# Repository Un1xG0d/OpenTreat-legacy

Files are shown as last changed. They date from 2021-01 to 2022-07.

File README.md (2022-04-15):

<h1 align="center">
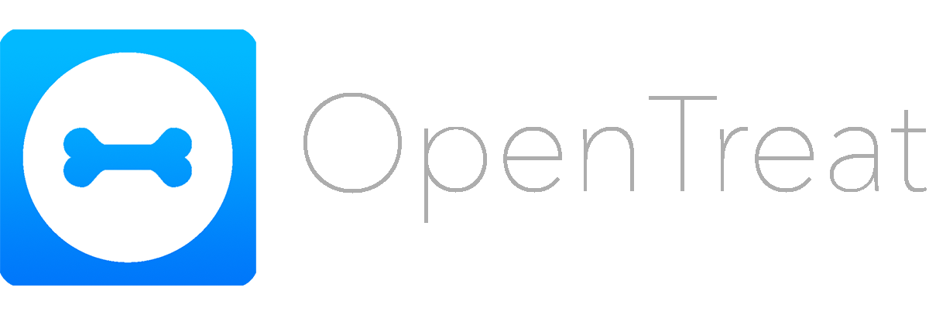
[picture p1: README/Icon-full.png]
  
</h1>

<div align="center">
	
	
	
</div>
<br>
<p>
OpenTreat allows a user to view and interact with their pets while not at home. Watch a live video stream of your pets from your smartphone or laptop, and remotely dispense treats with the push of a button.
</p>

:movie_camera: [Watch video demo of OpenTreat](https://youtu.be/6tzPRBlFip4) :movie_camera:

## Treat dispenser system
### Overview
The treat dispenser system is built using a Raspberry Pi and 3D printed parts. When a user presses the button on the webapp, a Python script is executed on the Pi to turn the servo motor for a certain number of seconds. The servo motor turns the 3D printed auger and pushes the treat down the tube where it drops out the end and into the feeding bowl.

### Parts needed
* Raspberry Pi
* LS3006 servo (any 360* servo should work)
* 3D printer
* USB webcam

### Physical assembly
1. Download and 3D print each STL listed in the `models` folder
	1. The recommended print settings are in the Resources section below
2. Assemble the parts using super glue
3. Use the pinout diagram in the Resources section (or find one for your RPi model) to hook up the 3 servo wires to the Raspberry Pi’s GPIO pins

### Configure ngrok
OpenTreat utilizes [ngrok](https://ngrok.com/docs) to securely expose the PHP pages to the internet. An annual Basic plan subscription allows you to create stable, custom subdomains for your dispensers. This is needed before running the script to populate the templates.

```
cd ~/
wget https://bin.equinox.io/c/4VmDzA7iaHb/ngrok-stable-linux-arm.tgz
tar xf ngrok-stable-linux-arm.tgz
/home/pi/ngrok authtoken 1hTfjOEDlX771y5WHDHL4bCZ1gc_81262WDRezREwGHuxX8pJ
```

### Register for free TURN server account
Create a free account on http://numb.viagenie.ca. You will need the server & login details you receive via email to run `populate_templates.sh`.

### Clone the repo into a folder called OpenTreat in your Pi's home directory
```
git clone https://github.com/psycoder17/OpenTreat.git ~/OpenTreat/src
cd ~/OpenTreat/src/
```

### Generate personalized files from code templates
```
bash populate_templates.sh
```

### Test the servo script on your Raspberry Pi
A Python3 script takes advantage of the Raspberry Pi’s GPIO pins to send a signal to the servo motor when a user presses the treat button on the webapp. The script turns the servo for a set number of seconds to push the treat through the tube and drop it down at the end.

### Install Python dependencies
```
pip3 install -r python/requirements.txt
```

### Manually execute the script to test that the servo/auger spins
```
python3 python/rotate_auger.py
```

Now that your Raspberry Pi properly dispenses treats when the Python script runs, Apache needs to be setup to host a PHP file that executes the Python script when the browser is redirected to `<Raspberry Pi IP>:80/spin.php`.

### Configure Apache server
```
sudo bash rpi-www/setup.sh
```

Then add `www-data ALL=(root) NOPASSWD: /sbin/reboot ` to your `/etc/sudoers` file to allow the www-data user to reboot the Pi.

At this point the servo connected to the RPi should now spin when visiting `<Raspberry Pi IP>/spin.php` in a web browser.

### Configure Apache secrets
Due to account restrictions and permission errors with the `www-data` user, we need to run the `broadcast_webcam.py` script as user `pi`. Instead of hardcoding the Pi's password into the project's source code, we can set an environment variable that reads from the file `/var/www/secrets/pipw`.

```
sudo mkdir /var/www/secrets/
sudo chown pi:root /var/www/secrets/
echo "PI_PW=<pi-user-account-password>" > /var/www/secrets/pipw
echo "NGROK_PW=<ngrok-basic-auth-password>" >> /var/www/secrets/pipw
```

> Remember to replace `<pi-user-account-password>` with the password you set for `pi` when initially configuring your Raspberry Pi. `<ngrok-basic-auth-password>` should be set here **and** as a Config Var on the Settings page of your Heroku application.

## Video stream app
The video streaming app is built with Javascript using NodeJS, Express, WebRTC, and Socket.IO. The webapp is hosted in Heroku and allows a user to login and view the video stream being broadcasted from the Pi's webcam.

### Deploy the video streaming app to Heroku
```
cd js/

heroku create <my-opentreat-project>

git add .
git commit -m "commit message"
git push heroku master
```

If everything was successful you can now browse to `https://<my-opentreat-project>.herokuapp.com/broadcast` on your Raspberry Pi to manually start broadcasting the Pi's webcam to your webapp on Heroku.

## Usage
### Automatic startup
Create a cronjob with `crontab -e` to run a Python script on boot to automatically broadcast the Pi's webcam to the webapp hosted on Heroku. The shell script configures and launches the ngrok tunnel.

```
@reboot python3 /var/www/html/broadcast_webcam.py
@reboot /bin/bash /var/www/html/ot_ngrok.sh
```

### View the video stream
On your smartphone or laptop, browse to `https://<my-opentreat-project>.herokuapp.com` to view the video stream of your pets. 
Press the bone button to spin the auger and drop treats into your pets' bowl. 
The orange button restarts the webcam broadcast.
The red button reboots the Raspberry Pi.

## Resources
### Links
[Viagenie.ca: free TURN servers](http://numb.viagenie.ca)

[Thingiverse: original fish feeder model](https://www.thingiverse.com/thing:301532)

[GitHub: original WebRTC broadcasting webapp](https://github.com/TannerGabriel/WebRTC-Video-Broadcast)

### Recommended print settings
> Scale: 100%  
> Infill: 30%  
> Layer Height: 0.2  
> Speed: Standard  
> Supports: None

### RPi GPIO diagram
> Red wire - Pin 1 - 3v3 power  
> Black wire - Pin 6 - ground  
> Orange wire - Pin 11 - GPIO 17  



### Screenshots & proof-of-concept
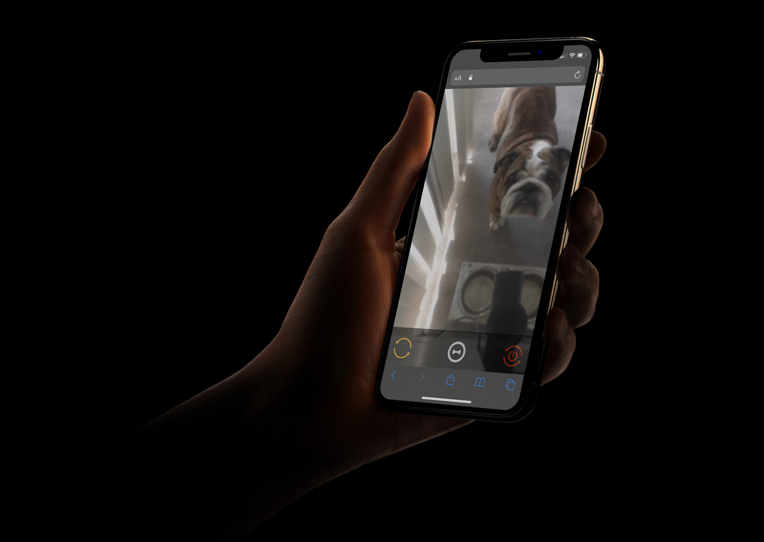
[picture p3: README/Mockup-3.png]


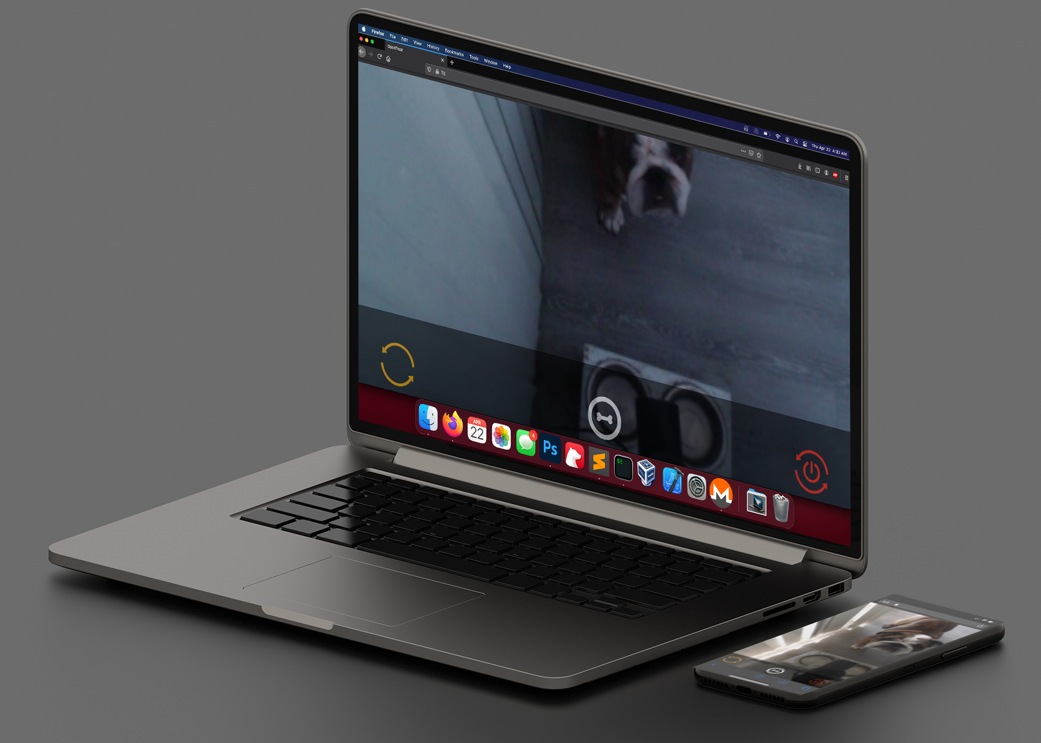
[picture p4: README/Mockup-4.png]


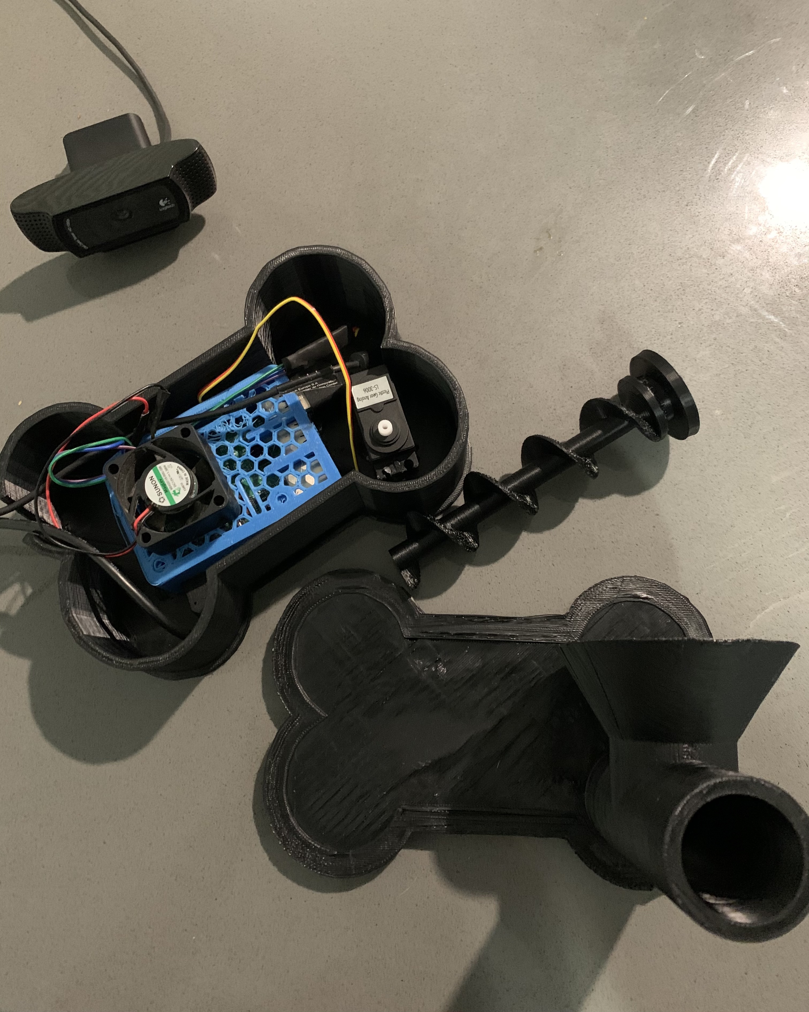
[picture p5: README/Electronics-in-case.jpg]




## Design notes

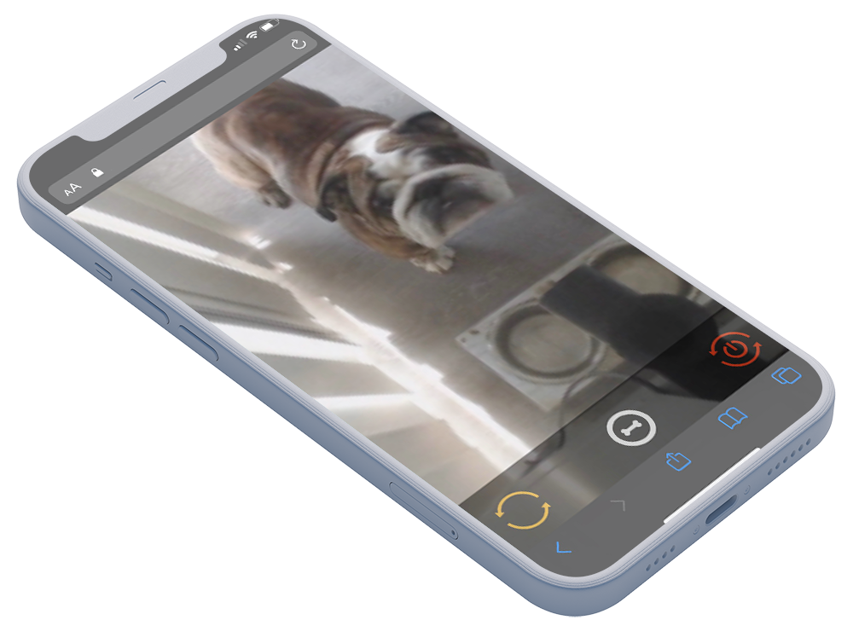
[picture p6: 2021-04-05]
README/Mockup-2.png

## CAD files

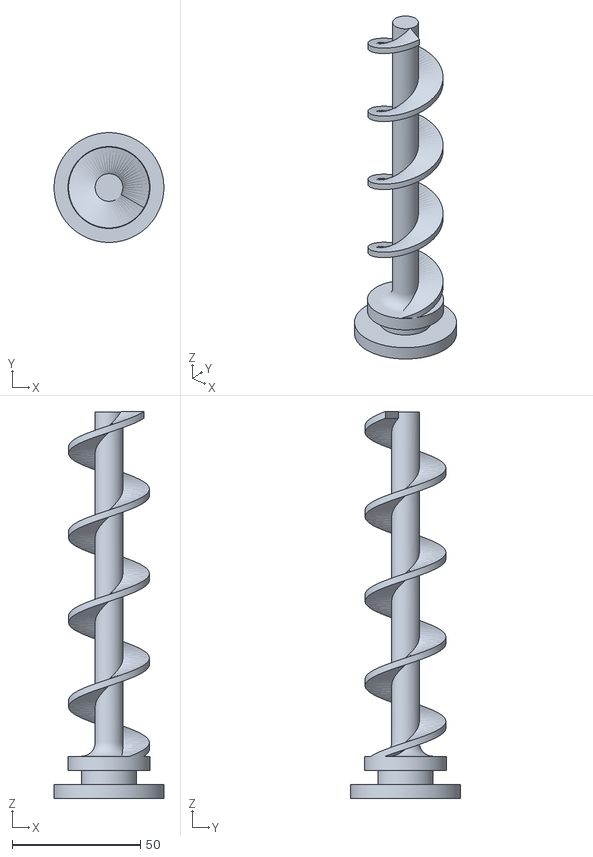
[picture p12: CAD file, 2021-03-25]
models/OpenTreat-auger.stl
42.8 x 42.8 x 151.0

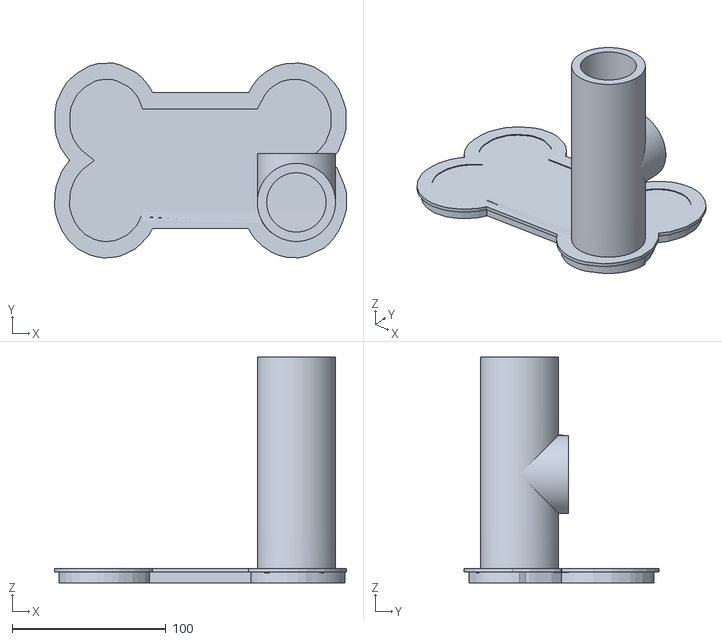
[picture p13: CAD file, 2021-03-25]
models/OpenTreat-top.stl
190.0 x 126.8 x 146.8

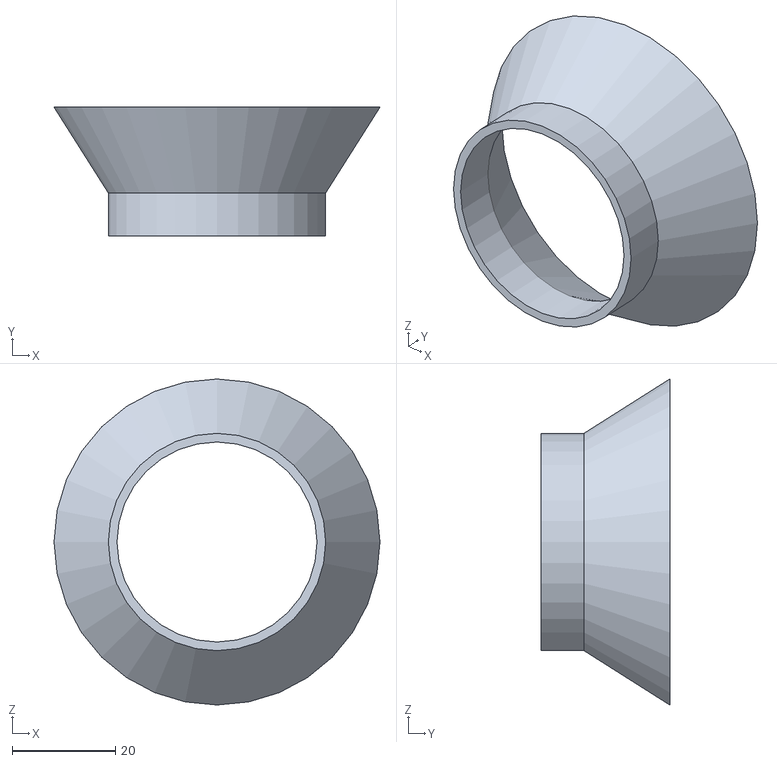
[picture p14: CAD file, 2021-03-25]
models/OpenTreat-hopper.stl
63.1 x 24.9 x 63.1

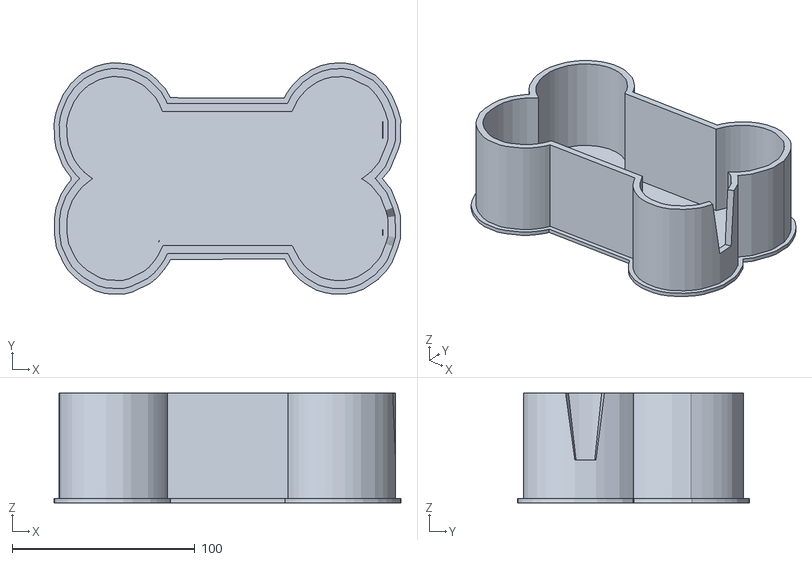
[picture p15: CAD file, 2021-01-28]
models/OpenTreat-bottom.stl
190.0 x 126.8 x 60.0

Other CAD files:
models/OpenTreat-assembly.blend

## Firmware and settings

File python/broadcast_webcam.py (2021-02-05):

from selenium import webdriver
from selenium.webdriver.chrome.options import Options
from selenium.webdriver.common.desired_capabilities import DesiredCapabilities

opt = Options()
opt.add_argument('--headless')
opt.add_argument('--use-fake-ui-for-media-stream')
opt.add_argument('--disable-web-security')
opt.add_argument("--remote-debugging-port=9222")
#Pass the argument 1 to allow and 2 to block
opt.add_experimental_option("prefs", { \
    "profile.default_content_setting_values.media_stream_mic": 2, 
    "profile.default_content_setting_values.media_stream_camera": 1,
    "profile.default_content_setting_values.geolocation": 2, 
    "profile.default_content_setting_values.notifications": 2 
  })

driver = webdriver.Chrome(executable_path='/usr/bin/chromedriver', options=opt)

driver.get('https://<my-opentreat-project>.herokuapp.com/broadcast.html')

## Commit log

2021-01-13 update recommended scale for 3D printed parts
2021-01-19 add button and logic to drop treat
2021-01-19 test code for streaming video on iOS devices
2021-01-28 export new STLs for updated 3D printed models
    [Auger.stl, Hopper.stl, Hopper_lid.stl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]
2021-01-28 add info about startup script to README, add photo of electronics in the 3D printed case, and include the final-ish video demo
2021-02-03 upgrade video streaming app to a more modern framework
2021-02-03 put back button to enable audio
2021-02-03 convert enable audio button to drop treat button and add function to open the PHP page
2021-02-03 add image for drop treat button
2021-02-03 fix drop treat button styling
2021-02-05 insert generic Heroku URL into Selenium's driver.get
2021-02-05 print success message for testing
2021-02-06 replace placeholder text in files in templates/ folder with variables collected from the developer by running populate_templates.sh
    [broadcast_webcam.py]
2021-02-06 remove my personal files as the correct files will be regenerated when running populate_templates.sh
    [broadcast_webcam.py]
2021-02-06 update recommended print settings
2021-02-06 add id to submit button
2021-02-06 click broadcast button on page authed
2021-02-07 add reboot button to view page
2021-02-07 add png for reboot button
2021-02-07 fix go button spacing when keyboard pops up
2021-02-07 update styling for restart buttons
2021-02-07 update watch.js template to include restartBroadcast button
2021-02-07 update spacing of restart buttons
2021-02-07 update mockup and README with latest layout and buttons
2021-02-07 update layout of restart buttons
2021-02-07 add home screen icon for iOS devices
2021-02-08 update recommended settings due to some of my prototypes breaking
2021-03-25 this version jams less due to better fitting parts
    [OpenTreat-assembly-v1.7.blend, OpenTreat-assembly.blend, OpenTreat-auger.stl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]
2021-04-06 add routes for restart buttons
2021-04-06 hide broadcast button to reduce user confusion
2021-04-22 hide broadcast button from view
